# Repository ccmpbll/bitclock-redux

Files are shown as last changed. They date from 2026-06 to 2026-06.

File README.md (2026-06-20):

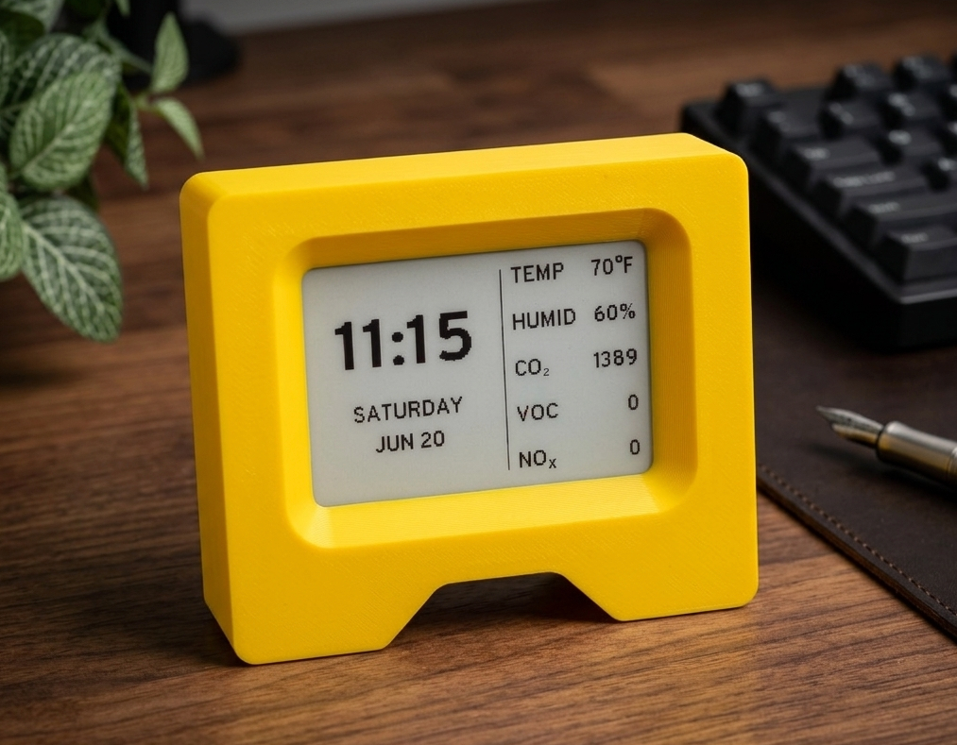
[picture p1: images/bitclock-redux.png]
bitclock redux


# bitclock-redux

A fork of [goat-hill/bitclock](https://github.com/goat-hill/bitclock) — an open-source e-ink desk clock and air quality monitor. This fork replaces the Bluetooth/BLE configurator with an on-device web admin and removes the weather feature to make it a clock-only device.

**Changes from upstream:**
- **Web admin** at `http://bitclock.local` — configure Wi-Fi, timezone, NTP server, and OTA firmware updates from any browser; no app or Bluetooth required
- **AP provisioning** — on first boot (or after a failed Wi-Fi connection), the device broadcasts a `bitclock-setup` Wi-Fi network with a setup page at `192.168.4.1`
- **Sensor readings on the clock face** — temperature, humidity, CO₂, VOC index, and NOx index displayed across the top of the display
- **MQTT + Home Assistant** — publishes all sensor readings to an MQTT broker; auto-discovery creates entities in Home Assistant automatically
- **BLE removed** — no Bluetooth stack; smaller firmware image
- **Weather removed** — clock-only device

## Flashing

### First install (USB)

Download `bitclock-redux-full-<version>.bin` from the [latest release](https://github.com/ccmpbll/bitclock-redux/releases/latest) and flash it at offset `0x0` using the [Espressif web flasher](https://espressif.github.io/esptool-js/) or [Adafruit WebSerial ESPTool
](https://adafruit.github.io/Adafruit_WebSerial_ESPTool/). The ESP32-S3 has native USB — no driver needed (shows as `/dev/cu.usbmodem*` on macOS).

### OTA update

Download `bitclock-redux-app-<version>.bin` from the [latest release](https://github.com/ccmpbll/bitclock-redux/releases/latest) and upload it via the web admin at `http://bitclock.local` → Firmware Update.

## Setup

1. On first boot, connect to the `bitclock-setup` Wi-Fi network
2. Open `http://192.168.4.1` in a browser and enter your Wi-Fi credentials
3. The device reboots into your network and is accessible at `http://bitclock.local`

## Sensor readings

Five values are displayed on the clock face and in the web admin:

| Reading | What it means |
|---|---|
| **Temp** | Ambient temperature (°C or °F) |
| **Humidity** | Relative humidity (%) |
| **CO₂** | Carbon dioxide in ppm. Fresh air is ~400 ppm; above 1000 ppm feels stuffy. Sensor range: 400–2000 ppm (±50 ppm + 5%). |
| **VOC** | Volatile organic compound index, relative to a rolling 24-hour baseline. **100** = baseline; **above 100** = air quality worsening (odors, fumes); **below 100** = cleaner than baseline. |
| **NOₓ** | Nitrogen oxide index. **1** = clean air; **above 1** = combustion byproducts detected (gas stove, smoke). |

## MQTT and Home Assistant

Bitclock can publish sensor readings to an MQTT broker and auto-discover itself in Home Assistant.

### Setup

1. In the web admin (`http://bitclock.local`), open the **MQTT** section
2. Enter your broker host, port (default 1883), and credentials if required
3. Set a topic prefix (default `bitclock`) and publish interval (default 30s)
4. Click **Save MQTT**

### Home Assistant

With the [MQTT integration](https://www.home-assistant.io/integrations/mqtt/) enabled in Home Assistant (discovery on by default), Bitclock will appear automatically as a device with 5 entities:

| Entity | Topic | Unit |
|---|---|---|
| Temperature | `bitclock/temp` | °C or °F (follows web admin setting) |
| Humidity | `bitclock/humidity` | % |
| CO₂ | `bitclock/co2` | ppm |
| VOC Index | `bitclock/voc` | — |
| NOx Index | `bitclock/nox` | — |

Discovery config topics are published with `retain=1` on connect, so Home Assistant picks them up even if it was offline when the device connected. Changing the temperature unit in the web admin updates the HA entity unit automatically on the next reconnect.

## Case

A 3D-printable case is available on [Printables](https://www.printables.com/model/1759743-bitclock-redux-case). STL and STEP files are also included in the [`case/`](case/) directory.

## Supported hardware

**PCB rev3a only** — the first and only commercially sold revision of the bitclock hardware (ESP32-S3, e-ink display). Earlier prototype revisions (rev1 ESP32-C3, Seeed ESP32-S3) are not supported by this fork and their build targets have been removed.

## Cloning

This repo uses git submodules.

```sh
git clone --recursive https://github.com/ccmpbll/bitclock-redux.git
```

If already cloned without `--recursive`:

```sh
git submodule init && git submodule update
```

## License

MIT — same as upstream. Original work by [goat-hill](https://github.com/goat-hill/bitclock).

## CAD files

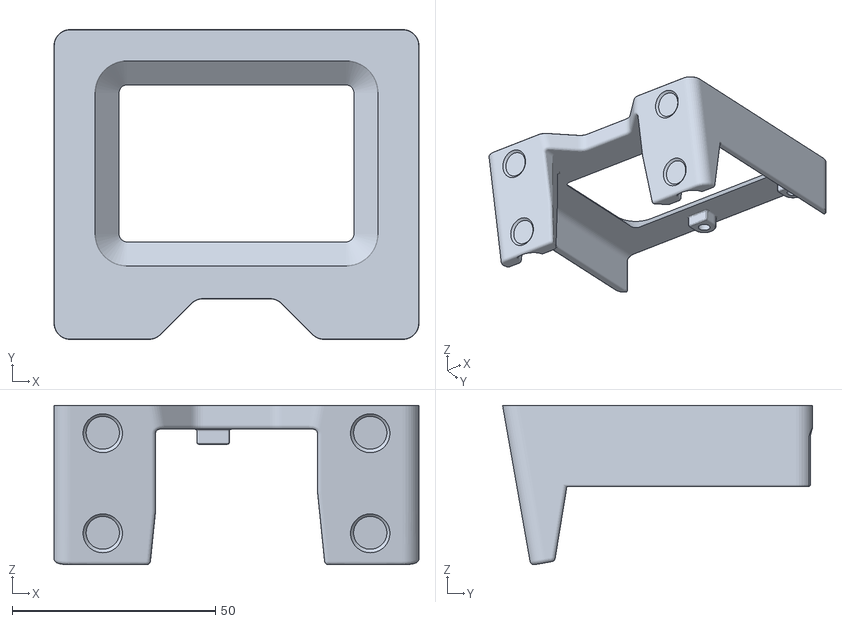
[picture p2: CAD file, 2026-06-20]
case/bitclock-redux case front.stl
89.8 x 76.2 x 39.2

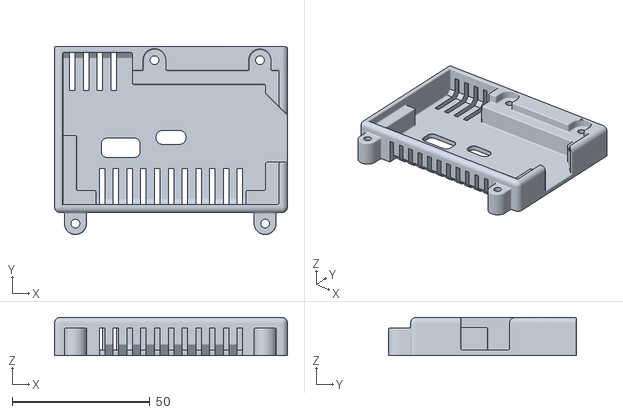
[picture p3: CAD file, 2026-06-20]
case/bitclock-redux case back.stl
84.5 x 68.2 x 13.8

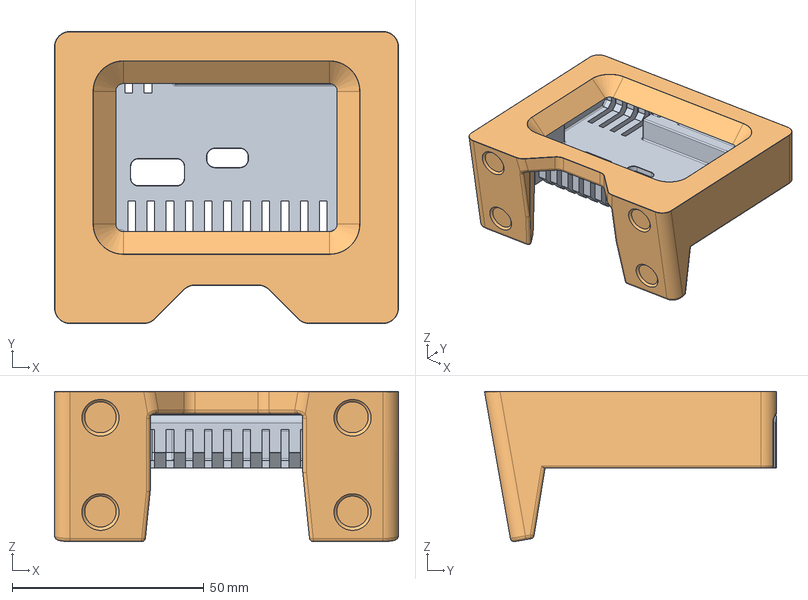
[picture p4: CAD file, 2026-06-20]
case/bitclock-redux case.step
89.8 x 76.2 x 39.2 mm

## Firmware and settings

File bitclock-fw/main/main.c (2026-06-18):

#include <stdio.h>
#include <stdlib.h>
#include <time.h>

#include "driver/gpio.h"
#include "driver/spi_master.h"
#include "esp_log.h"
#include "freertos/FreeRTOS.h"
#include "freertos/task.h"

#include "libs/i2c.h"
#include "libs/nvs.h"
#include "libs/ota.h"
#include "nvs_flash.h"
#include "pins.h"

#include "tasks/eink_display.h"
#include "tasks/led.h"
#include "tasks/scd4x.h"
#include "tasks/sgp4x.h"
#include "tasks/sharp_display.h"
#include "tasks/sht4x.h"
#include "tasks/tasks.h"
#include "tasks/wifi.h"

void app_main(void) {
  ESP_ERROR_CHECK(bitclock_ota_on_boot());
  i2c_bus_init();

  esp_err_t ret = nvs_flash_init();
  if (ret == ESP_ERR_NVS_NO_FREE_PAGES ||
      ret == ESP_ERR_NVS_NEW_VERSION_FOUND) {
    /* NVS partition was truncated
     * and needs to be erased */
    ESP_ERROR_CHECK(nvs_flash_erase());
    ESP_ERROR_CHECK(nvs_flash_init());
  }
  ESP_ERROR_CHECK(ret);
  ESP_ERROR_CHECK(bitclock_nvs_init());

  const char *tz = bitclock_nvs_get_tz();
  if (tz != NULL) {
    setenv("TZ", tz, 1);
    tzset();
  } else {
    setenv("TZ", "PST8PDT,M3.2.0,M11.1.0", 1);
    tzset();
  }

#ifdef LED_TASK_ENABLED
  ledTask = xTaskCreateStatic(led_task_run, "led",
                              LED_STACK_SIZE,    // ulStackDepth
                              (void *)1,         // pvParamters
                              LED_TASK_PRIORITY, // uxPriority
                              ledTaskStack,      // puxStackBuffer
                              &ledTaskBuffer     // pxTaskBuffer
  );
#endif

#ifdef DISP_TASK_ENABLED
#if DISPLAY_TYPE == DISPLAY_TYPE_SHARP
  dispTask = xTaskCreateStatic(disp_task_run, "display",
                               DISP_STACK_SIZE,    // ulStackDepth
                               (void *)1,          // pvParamters
                               DISP_TASK_PRIORITY, // uxPriority
                               dispTaskStack,      // puxStackBuffer
                               &dispTaskBuffer     // pxTaskBuffer
  );
#elif DISPLAY_TYPE == DISPLAY_TYPE_EINK
  einkTask = xTaskCreateStatic(eink_task_run, "eink",
                               EINK_STACK_SIZE,    // ulStackDepth
                               (void *)1,          // pvParamters
                               EINK_TASK_PRIORITY, // uxPriority
                               einkTaskStack,      // puxStackBuffer
                               &einkTaskBuffer     // pxTaskBuffer
  );
#endif
#endif // DISP_TASK_ENABLED

#ifdef SHT4X_TASK_ENABLED
  sht4xTask = xTaskCreateStatic(sht4x_task_run, "sht4x",
                                SHT4X_STACK_SIZE,    // ulStackDepth
                                (void *)1,           // pvParamters
                                SHT4X_TASK_PRIORITY, // uxPriority
                                sht4xTaskStack,      // puxStackBuffer
                                &sht4xTaskBuffer     // pxTaskBuffer
  );
#endif

#ifdef SCD4X_TASK_ENABLED
  scd4xTask = xTaskCreateStatic(scd4x_task_run, "scd4x",
                                SCD4X_STACK_SIZE,    // ulStackDepth
                                (void *)1,           // pvParamters
                                SCD4X_TASK_PRIORITY, // uxPriority
                                scd4xTaskStack,      // puxStackBuffer
                                &scd4xTaskBuffer     // pxTaskBuffer
  );
#endif

#ifdef SGP4X_TASK_ENABLED
  sgp4xTask = xTaskCreateStatic(sgp4x_task_run, "sgp4x",
                                SGP4X_STACK_SIZE,    // ulStackDepth
                                (void *)1,           // pvParamters
                                SGP4X_TASK_PRIORITY, // uxPriority
                                sgp4xTaskStack,      // puxStackBuffer
                                &sgp4xTaskBuffer     // pxTaskBuffer
  );
#endif

#ifdef WIFI_TASK_ENABLED
  wifiTask = xTaskCreateStatic(wifi_task_run, "wifi",
                               WIFI_STACK_SIZE,    // ulStackDepth
                               (void *)1,          // pvParamters
                               WIFI_TASK_PRIORITY, // uxPriority
                               wifiTaskStack,      // puxStackBuffer
                               &wifiTaskBuffer     // pxTaskBuffer
  );
#endif

  assert(gpio_install_isr_service(0) == ESP_OK);

  vTaskDelete(NULL);
}

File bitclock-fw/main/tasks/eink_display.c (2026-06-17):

//
// Driver for E2271KS0C1 / eScreen_EPD_271_KS_0C
//

#include "eink_display.h"

#if DISPLAY_TYPE == DISPLAY_TYPE_EINK

#include "driver/gpio.h"
#include "driver/spi_master.h"
#include "esp_log.h"
#include "freertos/FreeRTOS.h"
#include "freertos/task.h"
#include "libs/nvs.h"
#include "libs/sensor_utils.h"
#include "lvgl/lv_helper.h"
#include "lvgl/lvgl.h"
#include "lvgl/views/aqi_grid.h"
#include "lvgl/views/clock.h"
#include "lvgl/views/logo.h"
#include "lvgl/views/wifi_setup.h"
#include "scd4x.h"
#include "sgp4x.h"
#include "sht4x.h"
#include "tasks/wifi.h"
#include <math.h>
#include <string.h>
#include <time.h>

StaticTask_t einkTaskBuffer;
StackType_t einkTaskStack[EINK_STACK_SIZE];

#define INVERT_COLORS 0

static const char *TAG = "eink";

spi_device_handle_t spi;

#define DISPLAY_WIDTH 176
#define DISPLAY_HEIGHT 264

#define LVGL_WIDTH DISPLAY_HEIGHT
#define LVGL_HEIGHT DISPLAY_WIDTH

#define BUFFER_PIXEL_COUNT (40 * DISPLAY_WIDTH)

static lv_display_t *display;
static uint8_t lvgl_pixel_buffer[BUFFER_PIXEL_COUNT]
    __attribute__((aligned(LV_DRAW_BUF_ALIGN)));

static const uint8_t kDispAddrInputTemp = 0xe5;
static const uint8_t kDispAddrActiveTemp = 0xe0;
static const uint8_t kDispAddrPanelSettings = 0x00;
static const uint8_t kDispAddrOtp = 0xa2;
static const uint8_t kDispAddrFrame1 = 0x10;
static const uint8_t kDispAddrFrame2 = 0x13;
static const uint8_t kDispAddrPowerOn = 0x04;
static const uint8_t kDispAddrRefresh = 0x12;
static const uint8_t kDispAddrPowerOff = 0x02;
static const uint8_t kDispAddrVcomDataInterval = 0x50;

static const uint16_t kDispOtpBank0Addr = 0x0fb4;
static const uint16_t kDispOtpBank1Addr = 0x1fb4;

static const uint8_t kDispVcomCDI[] = {0x07};
static const uint8_t kDispVcomBorderSetting[] = {0x27};

static const uint8_t kDispDataPanelSettingsSoftReset[] = {0x0e};

#define DISP_ROW_LENGTH (DISPLAY_WIDTH / 8)
#define DISP_BYTES (DISP_ROW_LENGTH * DISPLAY_HEIGHT)
#define DISP_ROW_BEGIN(y) (DISP_ROW_LENGTH * y)
#define DISP_PIXEL_INDEX(x, y) (DISP_ROW_BEGIN(y) + x / 8)
#define DISP_PIXEL_BIT_MASK(x) (1 << (7 - (x % 8)))

DMA_ATTR static uint8_t disp_transfer_buffer[DISP_BYTES];
DMA_ATTR static uint8_t disp_transfer_buffer_prev[DISP_BYTES] = {0};
bool display_sync_needed = true;

// Display configuration read from on-device OTP memory
static uint8_t psr_data[2];

static void spi_init() {
  gpio_reset_pin(PIN_NUM_SPI_CLK);
  gpio_reset_pin(PIN_NUM_SPI_MOSI);
  gpio_reset_pin(PIN_NUM_SPI_CS_DISP);

  gpio_set_direction(PIN_NUM_SPI_CLK, GPIO_MODE_OUTPUT);
  gpio_set_direction(PIN_NUM_SPI_MOSI, GPIO_MODE_OUTPUT);
  gpio_set_direction(PIN_NUM_SPI_CS_DISP, GPIO_MODE_OUTPUT);

  gpio_set_level(PIN_NUM_SPI_CLK, 0);
  gpio_set_level(PIN_NUM_SPI_MOSI, 0);
  gpio_set_level(PIN_NUM_SPI_CS_DISP, 0);

  spi_bus_config_t buscfg = {.mosi_io_num = PIN_NUM_SPI_MOSI,
                             .miso_io_num = -1,
                             .sclk_io_num = PIN_NUM_SPI_CLK,
                             .quadwp_io_num = -1,
                             .quadhd_io_num = -1,
                             .max_transfer_sz = DISP_BYTES};

  spi_bus_initialize(SPI2_HOST, &buscfg, SPI_DMA_CH_AUTO);
}

static esp_err_t eink_spi_add_device(uint32_t clock_speed) {
  spi_device_interface_config_t devcfg = {
      .clock_speed_hz = clock_speed,
      .mode = 0,
      .flags = SPI_DEVICE_HALFDUPLEX | SPI_DEVICE_3WIRE,
      .spics_io_num = PIN_NUM_SPI_CS_DISP,
      .queue_size = 1,
  };
  return spi_bus_add_device(SPI2_HOST, &devcfg, &spi);
}

static esp_err_t eink_spi_remove_device() { return spi_bus_remove_device(spi); }

static void disp_spi_send_cmd(spi_device_handle_t spi, const uint8_t addr,
                              const uint8_t *data, int data_len) {
  // Note that for uint8_t, most significant bit is sent first
  esp_err_t ret;
  static spi_transaction_t t = {.flags = SPI_TRANS_USE_TXDATA |
                                         SPI_TRANS_DMA_BUFFER_ALIGN_MANUAL,
                                .length = 8,
                                .user = (void *)1};
  t.tx_data[0] = addr;

  gpio_set_level(PIN_NUM_DISP_DC, 0);
  ret = spi_device_polling_transmit(spi, &t);
  gpio_set_level(PIN_NUM_DISP_DC, 1);

  if (ret != ESP_OK) {
    ESP_LOGE(TAG, "Failed to SPI transmit: %u", ret);
    return;
  }

  for (uint16_t i = 0; i < data_len; i++) {
    t.tx_data[0] = data[i];
    ret = spi_device_polling_transmit(spi, &t);
    if (ret != ESP_OK) {
      ESP_LOGE(TAG, "Failed to SPI transmit: %u", ret);
      return;
    }
  }

  ESP_LOGD(TAG, "Successfully sent %u bytes to SPI command to addr: 0x%02x",
           data_len, addr);
}

static void disp_spi_send_data_byte(spi_device_handle_t spi,
                                    const uint8_t data) {
  esp_err_t ret;
  static spi_transaction_t t = {.flags = SPI_TRANS_USE_TXDATA |
                                         SPI_TRANS_DMA_BUFFER_ALIGN_MANUAL,
                                .length = 8,
                                .user = (void *)1};
  t.tx_data[0] = data;
  ret = spi_device_polling_transmit(spi, &t);
  if (ret != ESP_OK) {
    ESP_LOGE(TAG, "Failed to SPI transmit data byte: %u", ret);
  }
}

static void disp_send_frame(uint8_t *tx_buffer) {
  esp_err_t ret;
  static spi_transaction_t t = {.flags = SPI_TRANS_DMA_BUFFER_ALIGN_MANUAL,
                                .length = DISP_BYTES * 8,
                                .user = (void *)1};
  t.tx_buffer = tx_buffer;
  ret = spi_device_polling_transmit(spi, &t);
  if (ret != ESP_OK) {
    ESP_LOGE(TAG, "Failed to SPI transmit frame: %u", ret);
  }
}

static void eink_gpio_init() {
  gpio_reset_pin(PIN_NUM_DISP_DC);
  gpio_reset_pin(PIN_NUM_DISP_RST);
  gpio_reset_pin(PIN_NUM_DISP_BUSY);

  gpio_set_direction(PIN_NUM_DISP_DC, GPIO_MODE_OUTPUT);
  gpio_set_direction(PIN_NUM_DISP_RST, GPIO_MODE_OUTPUT);
  gpio_set_direction(PIN_NUM_DISP_BUSY, GPIO_MODE_INPUT);

  gpio_set_level(PIN_NUM_DISP_DC, 0);
  gpio_set_level(PIN_NUM_DISP_RST, 0);
}
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

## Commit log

2026-06-16 Add AP provisioning mode for Wi-Fi setup
    On first boot (no saved credentials) or after 10 failed STA connection
    attempts at boot, the device starts a 'bitclock-setup' open AP and serves
    a captive HTTP setup page at 192.168.4.1. The page scans for nearby
    networks, presents a dropdown, and accepts a password. On submit, credentials
    are saved to flash and the device reboots into normal STA mode.
    Mid-session disconnects use silent unlimited retry and never trigger AP mode.
    BLE provisioning continues to work alongside AP mode unchanged.
    New files:
    - tasks/wifi_ap.c/.h: AP lifecycle, HTTP server, scan, form handling
    - lvgl/views/wifi_setup.c/.h: e-ink setup screen (first-boot and fallback varian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
    [eink_display.c]
2026-06-17 Phase 1: on-device web admin server (settings, readings, wifi, OTA)
    Adds a persistent esp_http_server that starts in STA mode once Wi-Fi connects,
    reachable at the device IP or http://bitclock.local via mDNS.
    - web/admin.html: vanilla-JS admin page styled like bitclock.io
    - web/tz.json: timezone table generated from the web app's tz.ts (scripts/gen_tz.py)
    - tasks/web_admin.c: HTTP server with endpoints:
    GET / admin page
    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
2026-06-17 Show sensor readings on clock face, replacing the alert indicator
    - Clock face now shows temp/humidity (top row) and CO2/VOC/NOx (second row)
    across the top, sourced from the shared aqi data, respecting the temp unit
    - Removed the aqi_alert fan/label from the clock view
    - Added degree and percent glyphs to the sublabel font
    - Populate humidity_pct in shared aqi data (was never set)
2026-06-17 Fix web admin: NaN-safe status JSON, no dropdown clobbering, friendly weather lookup
    - status JSON now emits 0 for non-finite sensor floats; NaN printed as 'nan'
    was invalid JSON and broke all readings + dropdowns on load (#1, #5)
    - settings controls are populated once on load; polling only updates the live
    readings, so an in-progress dropdown selection is no longer overwritten (#2)
    - weather location: enter lat/lon and look up via the NWS points API in the
    browser, which resolves the gridpoint forecast path automatically (#3)
    - fetch failures no longer clear existing readings to blanks
2026-06-17 fix: timezone dropdown preselection and sensor readings single-row layout
    Set sel.value after populating options rather than o.selected=true inside
    the loop — setting selected before appending to the DOM is unreliable and
    caused the timezone dropdown to not reflect the saved value after reload.
    Also fixed the sensor readings grid to use repeat(5, 1fr) so all five
    readings always render on a single line.
2026-06-17 fix: disable BT in sdkconfig; harden page-load retry
    CONFIG_BT_ENABLED=y with the BT stack removed from CMakeLists left the
    WiFi/BT SW coexistence arbitrator active but BT uninitialised — causing
    the arbitrator to unnecessarily throttle WiFi RX, which made the HTTP
    server intermittently unresponsive on page refresh.
    Changes:
    - sdkconfig: set CONFIG_BT_ENABLED=n, remove orphaned NimBLE/CTRL
    sections, disable CONFIG_ESP_COEX_SW_COEXIST_ENABLE (WiFi-only mode)
    - sdkconfig.defaults: drop all BT/NimBLE entries; add SOFTAP=y and
    LWIP_MAX_SOCKETS=16 so they are canonical in the defaults file
    - admin.html: loadTimezones() returns bool; initSettings() propagates
    it; init() retries the full s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
2026-06-17 chore: remove dead code left over from weather and BLE removal
    Deleted files (never reached from any live code path):
    - libs/aqi_alert.c/h — alert thresholds computed but alert widget
    (lv_helper_aqi_alert_create/update) was never called on eink path
    - libs/http_buffer.c/h — 24 kB response buffer for the removed weather API
    - lvgl/views/aqi_alert.c/h — alert overlay widget, create/update never called
    Simplified eink_display.c:
    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
2026-06-17 chore: remove enclosure, PCB, web app; consolidate tz source into scripts/
    The enclosure STLs and PCB KiCad files are not needed for firmware
    development. The Next.js web app (bitclock-web) relied on BLE for device
    configuration, which was removed in v1.3.3; the on-device web admin
    replaces it entirely.
    - Delete bitclock-enclosure/ (STL files)
    - Delete bitclock-pcb/ (KiCad schematics + Gerbers)
    - Delete bitclock-web/ (Next.js app, ~106k lines)
    - Delete scripts/gen_uuid.py (generated BLE service UUIDs, BLE is gone)
    - Move scripts/tz.ts here from bitclock-web/src/libs/tz.ts — this is the
    single source of truth for the timezone table; edit it and re-run
    scripts/gen_tz.py to regenerate bi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
    [back.stl, bom-jlcpcb.csv, bom.csv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]
2026-06-17 fix: restore aqi_grid.h include in eink_display.c
    [eink_display.c]
2026-06-17 docs: add sensor reading explanations to README and web admin
    Add a Sensor readings table to the README explaining CO2, VOC, and NOx
    scales. Add matching hint text below the readings card in the web admin.
    Also fix page title from "bitclock-redux Admin" to "bitclock-redux".
2026-06-17 feat: split clock face — time/date left, sensors right
2026-06-17 feat: add divider line between clock and sensor panels
2026-06-17 feat: MQTT integration with Home Assistant discovery
    Publishes sensor readings to a configurable MQTT broker. On connect,
    sends HA MQTT discovery config topics (retain=1) for all 5 sensors so
    they appear automatically in Home Assistant. State topics publish every
    30 seconds. Broker config (host, port, user, pass, topic prefix) is
    stored in NVS and editable via the web admin MQTT card.
2026-06-17 fix: remove kStopPeriodicMeasurement constant orphaned by previous cleanup
    [scd4x.c]
2026-06-18 fix: null checks on malloc in nvs_init, correct sgp4x task name
    [main.c]
2026-06-20 docs: add 3D-printable case files (STL + STEP)
    [bitclock-redux case back.stl, bitclock-redux case front.stl, bitclock-redux case.step]
2026-06-20 docs: add case section to README with Printables link
